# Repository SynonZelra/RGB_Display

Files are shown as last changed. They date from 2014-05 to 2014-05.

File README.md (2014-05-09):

RGB Display
===========	
During my work term at Lumotune I worked with developed LCD drivers and wanted to try a completely different type of display that I would be able to make on my own so I looked into making a RGB display. Just like the LED cube, multiplexing and persistence of vision were key techniques required. I used PWM drivers (TLC5940) to drive the specific values to the RGB LEDs in each column and shift registers (CD4094B) to switch between the rows. 
This is the first personal project dealing with complex IC so an online tutorial and base TLC5940 code from Kevin Darrah was used and expanded on: https://www.youtube.com/watch?v=FehBLNHMlfo 

This code was used instead of existing libraries to understand lower level programming and in depth use of TLC5940.
	
Updates:
--------
-	Original design was for 32 columns. This was reduced to 16 columns due to lack of RGB LEDs. The other sections have been updated to take this change into account.

Here is an image of the 16x16 RGB Display:  
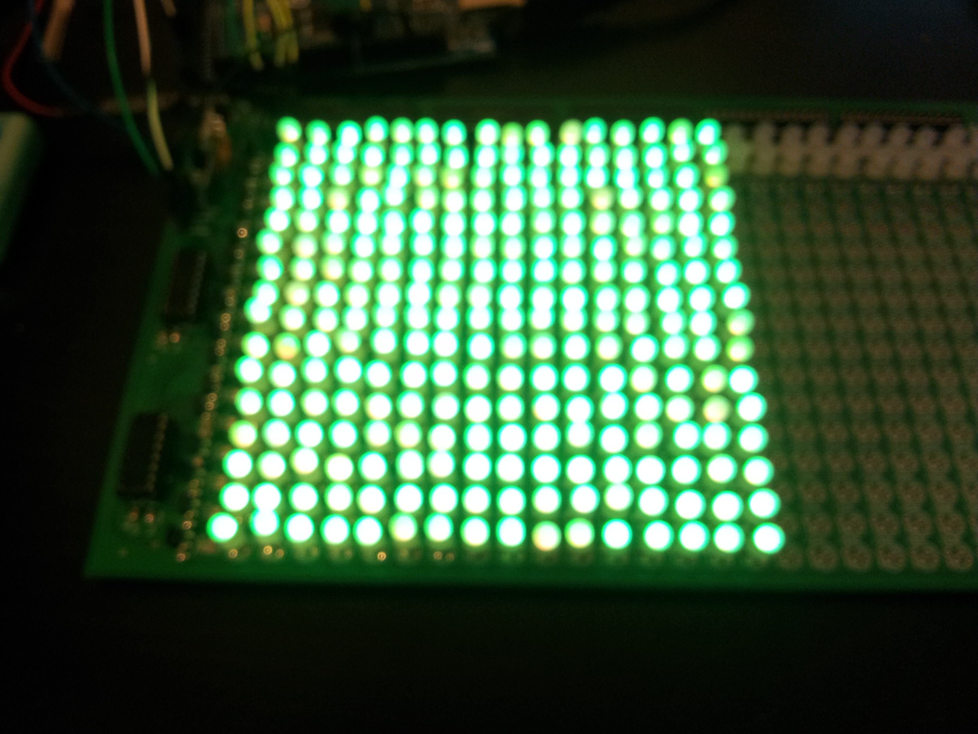
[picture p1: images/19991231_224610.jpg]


Click below for a video of the display:  
<a href="https://youtu.be/2PrOFA3ZqBM">https://youtu.be/2PrOFA3ZqBM</a>

Materials:
----------
(Material list has been updated)
-	x256, 5mm RGB LED
    -	Common anode for PWM driver to sink current, see Figure 1
-	x3, PWM driver [TLC5940](http://www.ti.com/lit/ds/symlink/tlc5940.pdf)
    -	16 channels per chip
    -	12-bit PWM resolution
    -	6-bit dot correction resolution
    -	Current sink
    -	Daisy-chained
-	x2, shift register [CD4094B](http://www.ti.com/lit/ds/symlink/cd4094b.pdf)
    -	8 outputs per chip
    -	Daisy-chained
-	x16, p-channel MOSFET [ZVP4424A](http://www.diodes.com/datasheets/ZVP4424A.pdf) 
-	x5, 0.1uF ceramic capacitor, package 0805
-	x5, 1uF ceramic capacitor, package 0805
-	x2, 10uF tantalum capacitor
-	x1, 5V LDO regulator [LT1096CT](http://cds.linear.com/docs/en/datasheet/1086ffs.pdf)
-	x2, 1x6 female connector header
-	x1, 2.1mm power connector jack
-	x3, 28 position IC socket 
-	Soldering assembly (solder, iron, braid, etc.)
-	Breadboard and jumper wires

Design:
-------
-	LEDs were arranged in an array of 16x16 (256 LEDs, 48 pins per row) addressed by 3 PWM drivers (48 channels) and 2 shift registers (16 outputs)
-	Column data input to PWM drivers through SPI protocol, lighting an entire row at once and row is switched with shift register and new RGB data is sent through PWM driver
-	Shift register can’t source enough current to light 16 LEDs so a p-channel MOSFET is used as a high side switch at each row to source required current
-	Base code from Kevin Darrah included:
    -	8-bit to 12-bit conversion for GS data transmission
    -	SPI protocol and timer interrupt setup 
-	Code was expanded on to include:
    -	Brightness and colour correction
    -	8-bit data resolution for easier storage and processing
    -	Shift register, data buffer and multiplexing
-	Schematic capture and PCB layout designed with CadSoft EAGLE

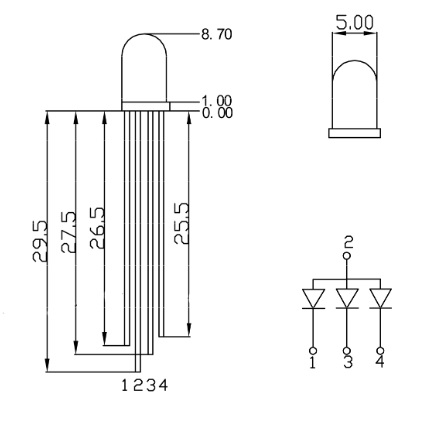
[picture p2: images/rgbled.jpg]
  
Figure 1: Common Anode RGB LED

Assembly:
---------
Prototype and assembly of RGB display can be seen from the images and videos below:  
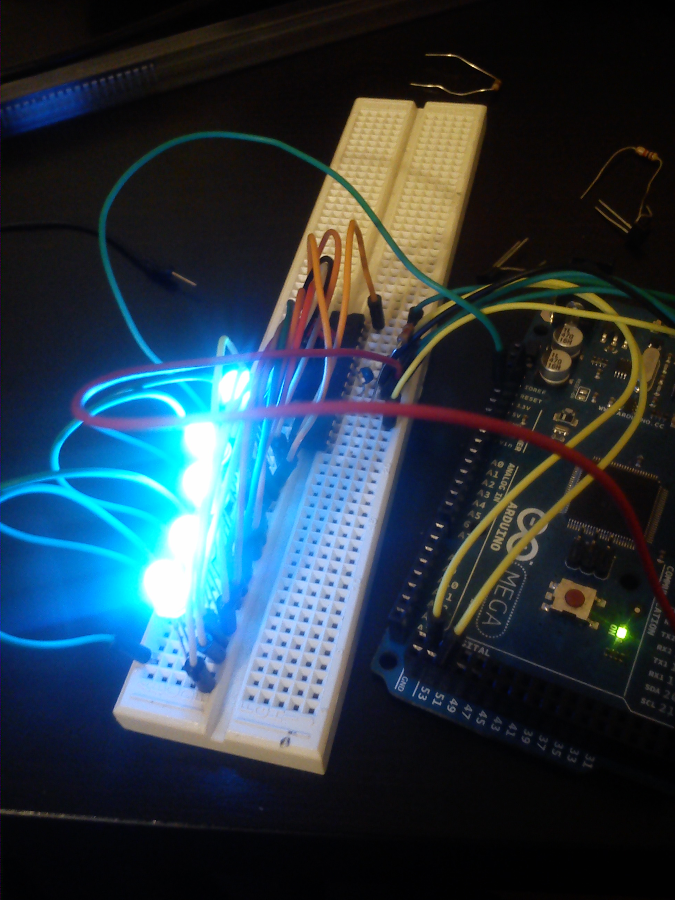
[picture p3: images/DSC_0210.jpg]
  
Figure 2: Testing TLC5940 

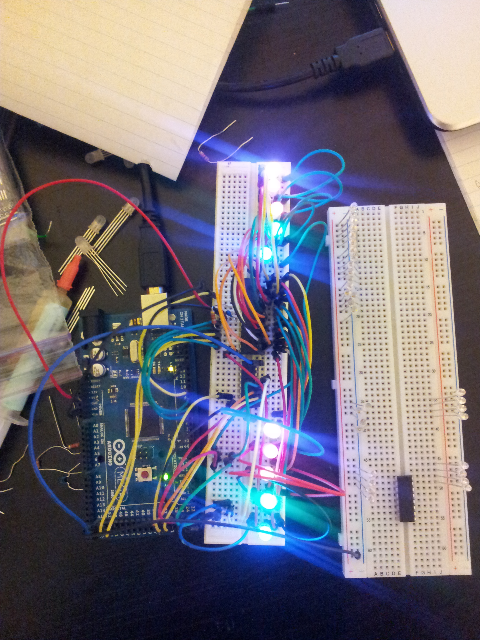
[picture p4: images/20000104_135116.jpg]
  
Figure 3: 0000104_135116, Testing 2 row multiplexing with TLC5940 and CD4094B  

<a href="https://youtu.be/0XYK6YoSBJY">https://youtu.be/0XYK6YoSBJY</a>  
Video 1: TLCCycle2, Video of cycling through all the colours with TLC5940

<a href="https://youtu.be/0XYK6YoSBJY">https://youtu.be/0XYK6YoSBJY</a>  
Video 2: TLCShift, Video of shifting colours with TLC5940

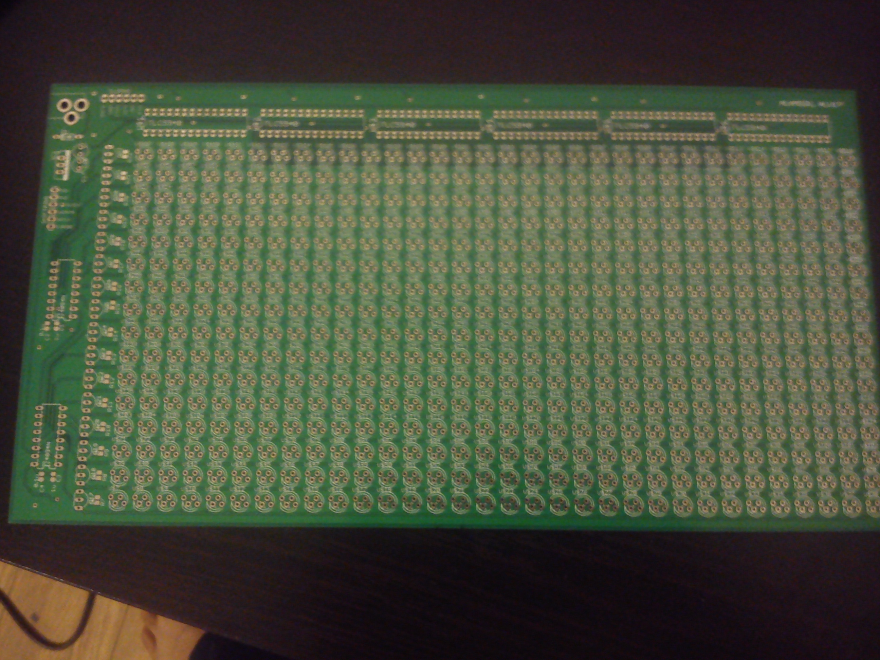
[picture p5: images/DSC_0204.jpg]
  
Figure 4: PCB from SeeedStudio

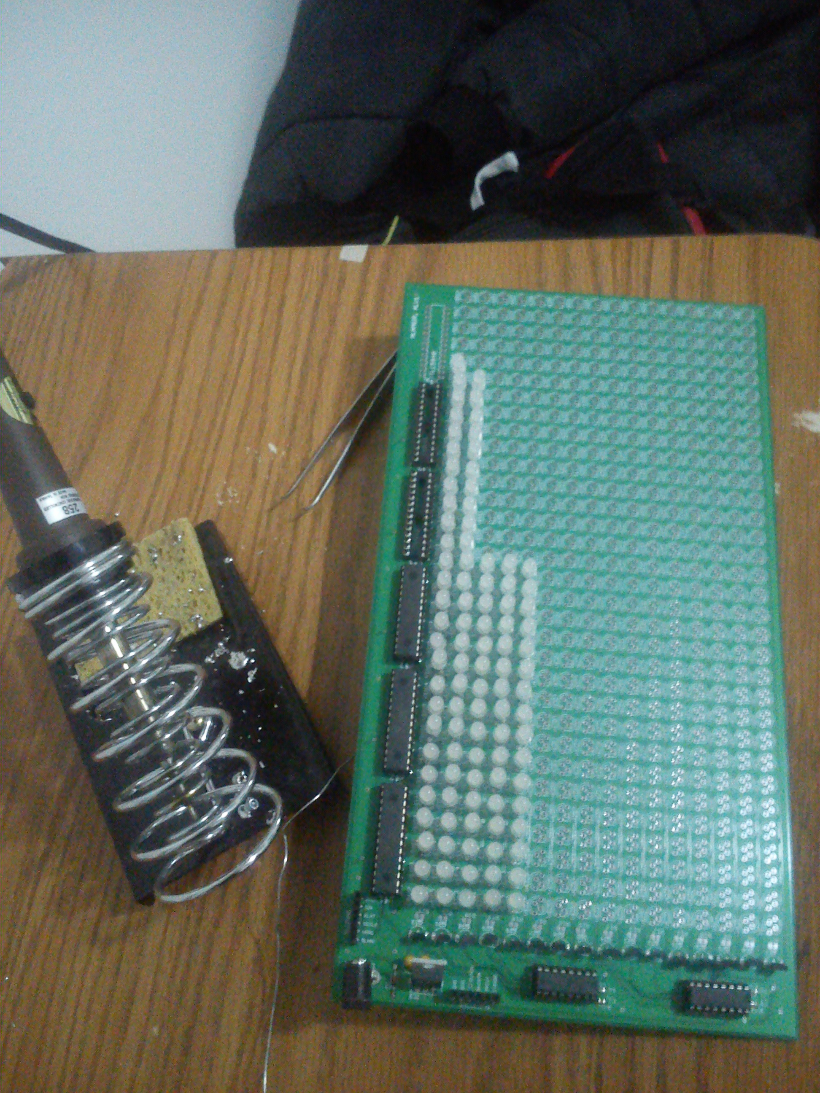
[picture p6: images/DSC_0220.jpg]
  
Figure 5: Soldering the PCB

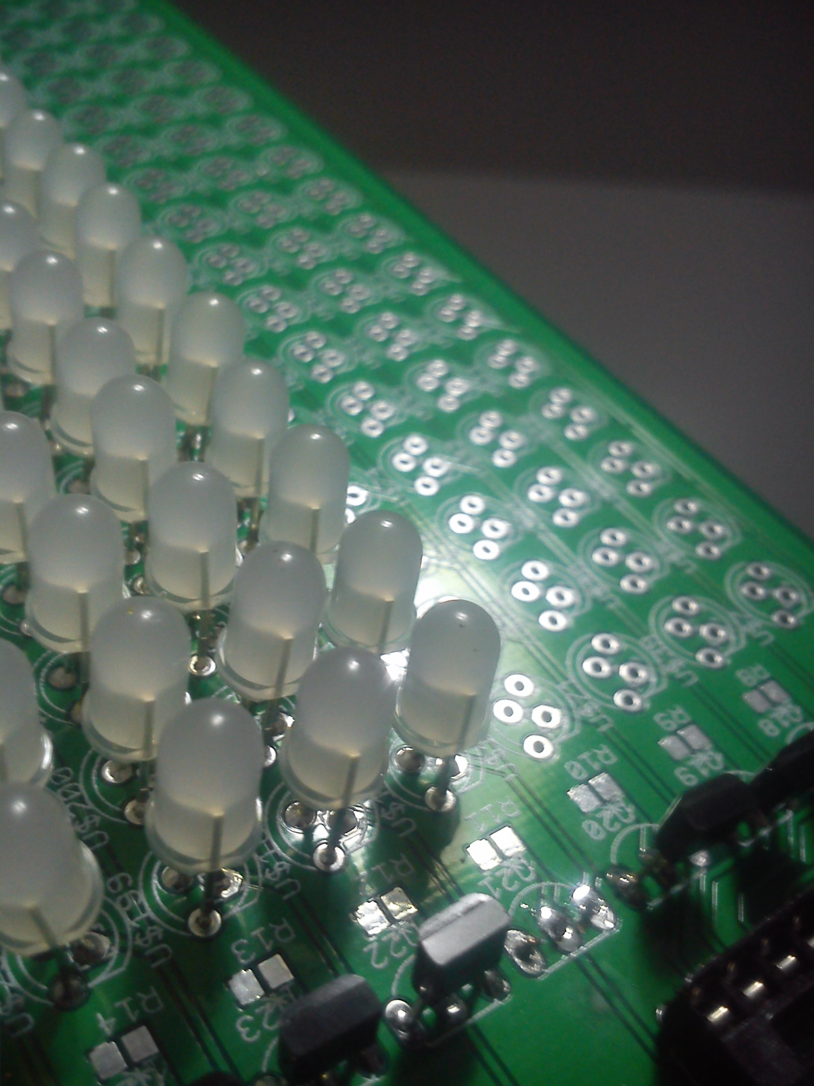
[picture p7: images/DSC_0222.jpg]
  
Figure 6: Testing and debugging the board (malfunctioning MOSFET) while soldering 

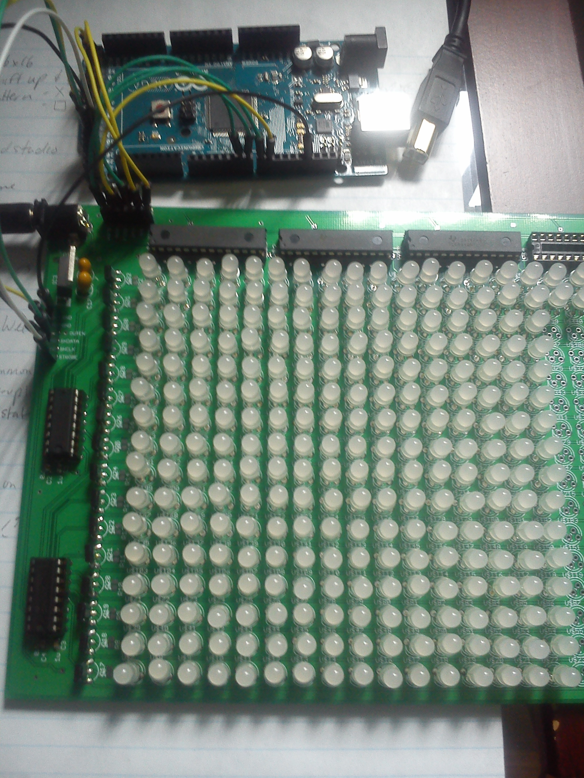
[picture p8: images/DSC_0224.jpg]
  
Figure 7: 16x16 RGB LED soldered!

Future:
-------
-	Update software to use TLC5940 and TLC5940Mux libraries
-	Import images with Python through serial port and show on RGB display

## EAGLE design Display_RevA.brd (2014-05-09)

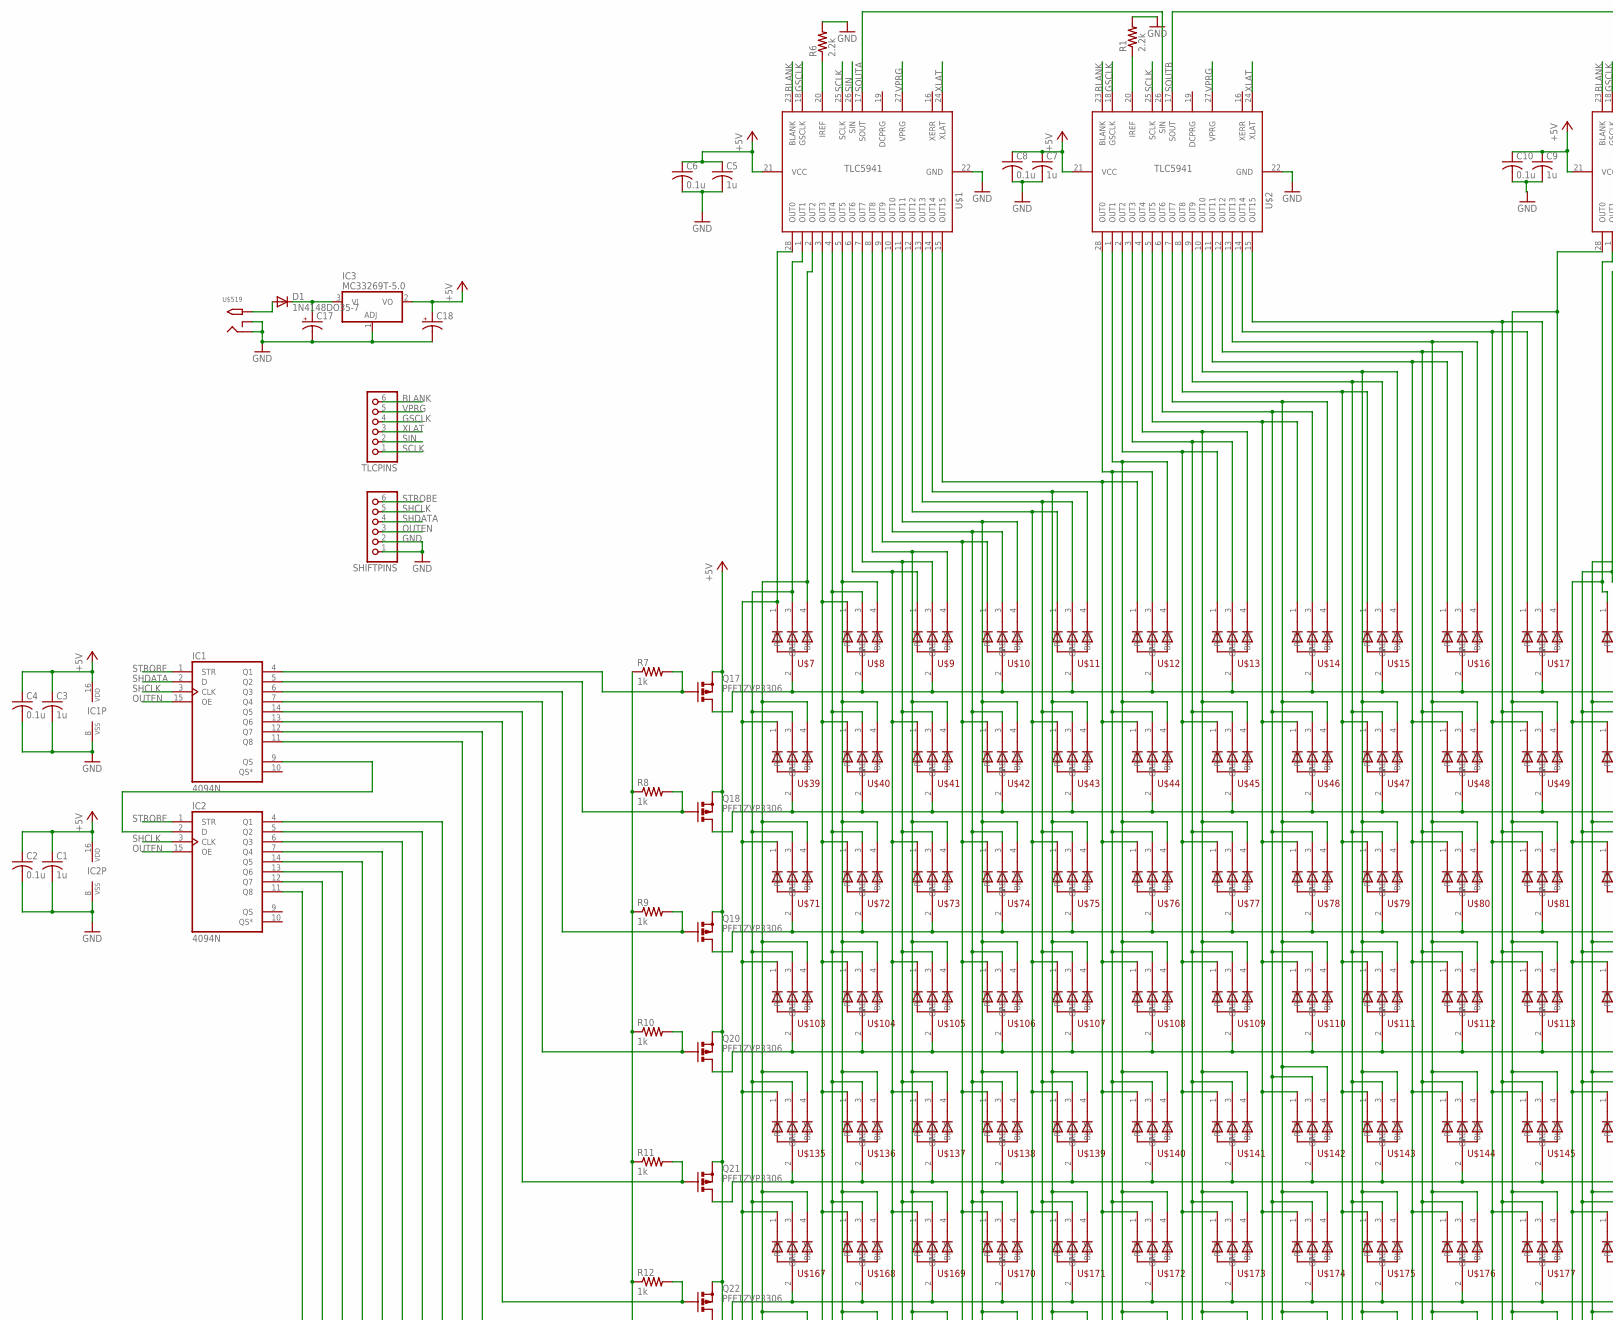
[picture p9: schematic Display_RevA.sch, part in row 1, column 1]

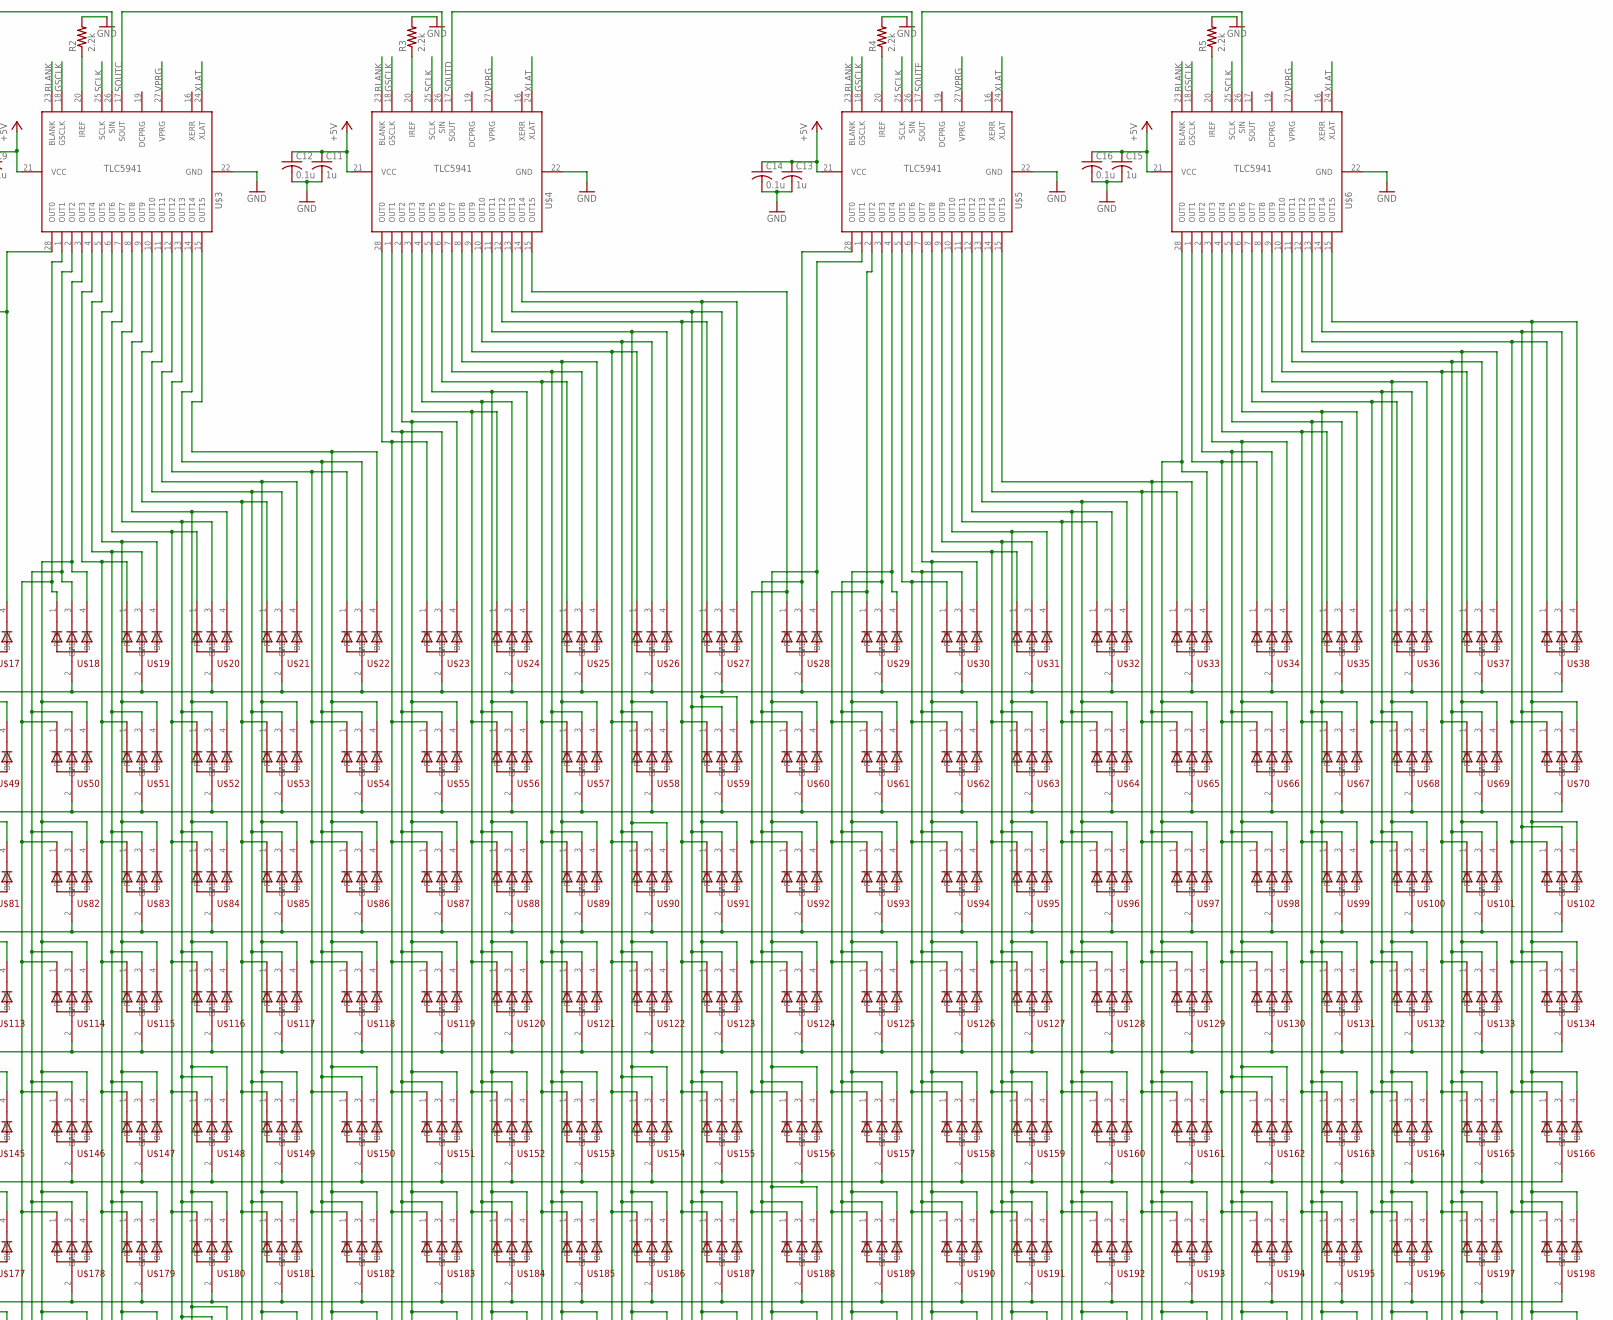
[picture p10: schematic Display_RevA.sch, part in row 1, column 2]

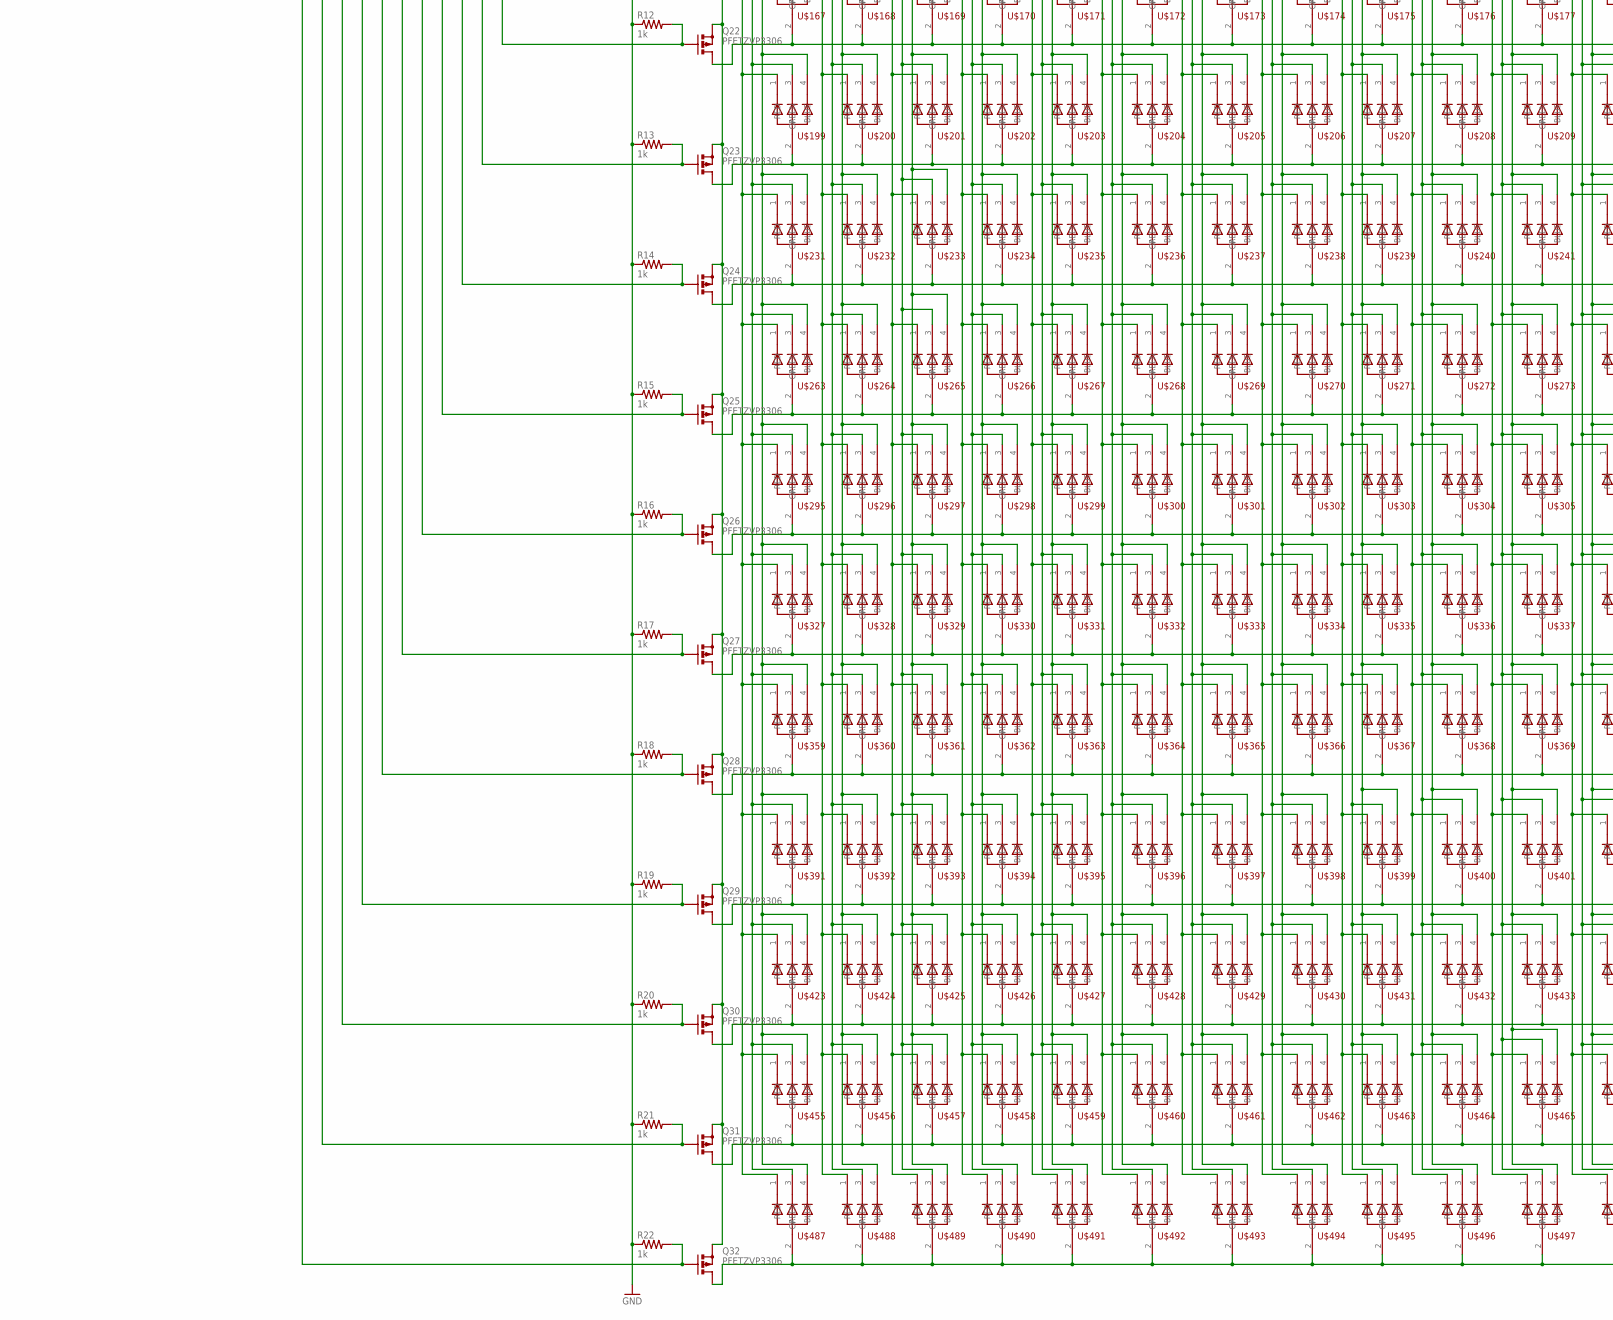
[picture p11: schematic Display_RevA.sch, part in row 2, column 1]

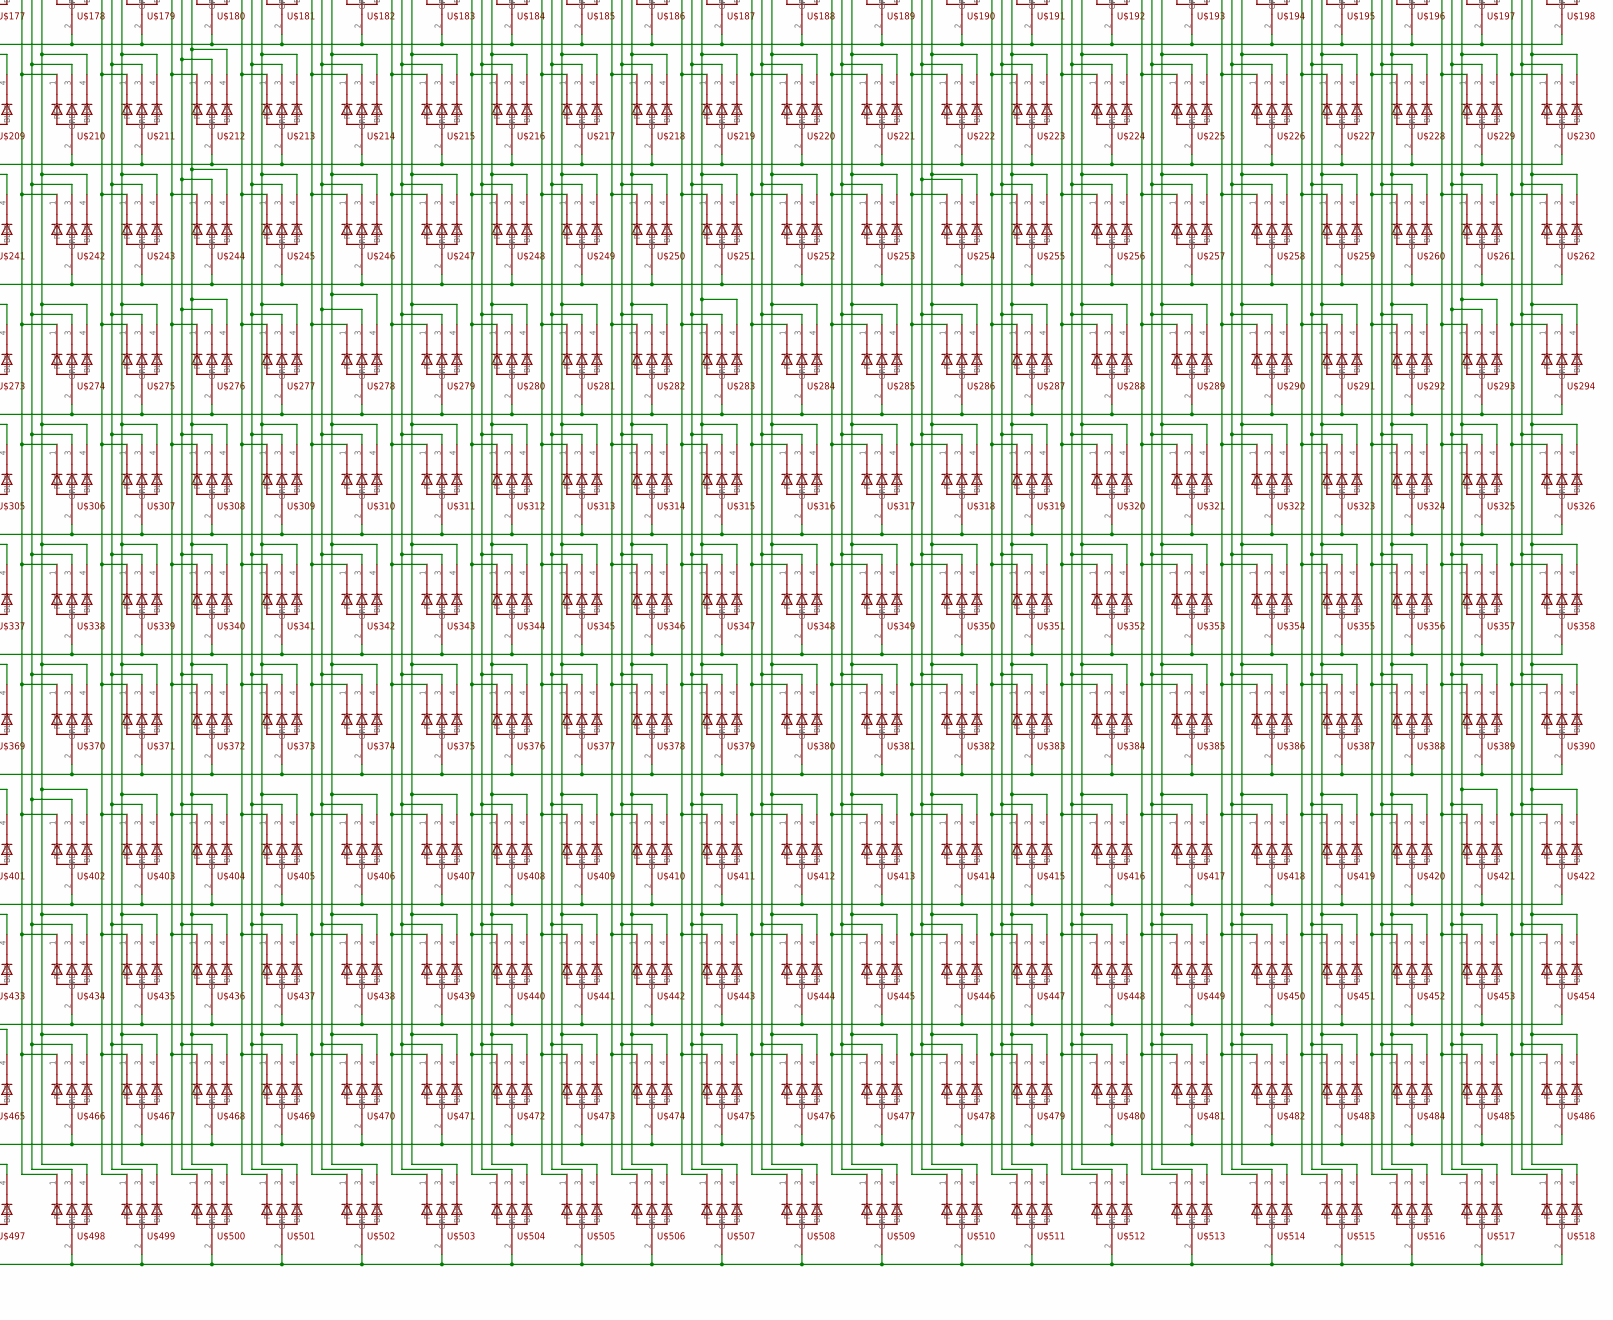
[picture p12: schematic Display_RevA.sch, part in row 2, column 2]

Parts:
C1, C3, C5, C7, C9, C11, C13, C15: 1u; C0805
C2, C4, C6, C8, C10, C12, C14, C16: 0.1u; C0805
C17, C18: CPOL-USE2.5-5; E2,5-5
D1: 1N4148DO35-7; DO35-7
IC1, IC2: 4094N; DIL16
IC3: MC33269T-5.0; TO220V
Q17, Q18, Q19, Q20, Q21, Q22, Q23, Q24, Q25, Q26, Q27, Q28, Q29, Q30, Q31, Q32: PFETZVP3306; TO92-OVAL
R1, R2, R3, R4, R5, R6: 2.2k; R0805
R7, R8, R9, R10, R11, R12, R13, R14, R15, R16, R17, R18, R19, R20, R21, R22: 1k; R0805
SHIFTPINS: PINHD-1X6; 1X06
TLCPINS: PINHD-1X6; 1X06
U$1, U$2, U$3, U$4, U$5, U$6: TLC5940; DIL28-3
U$7, U$8, U$9, U$10, U$11, U$12, U$13, U$14, U$15, U$16, U$17, U$18, U$19, U$20, U$21, U$22, U$23, U$24, U$25, U$26, U$27, U$28, U$29, U$30, U$31, U$32, U$33, U$34, U$35, U$36, U$37, U$38, U$39, U$40, U$41, U$42, U$43, U$44, U$45, U$46, U$47, U$48, U$49, U$50, U$51, U$52, U$53, U$54, U$55, U$56, U$57, U$58, U$59, U$60, U$61, U$62, U$63, U$64, U$65, U$66, U$67, U$68, U$69, U$70, U$71, U$72, U$73, U$74, U$75, U$76, U$77, U$78, U$79, U$80, U$81, U$82, U$83, U$84, U$85, U$86, U$87, U$88, U$89, U$90, U$91, U$92, U$93, U$94, U$95, U$96, U$97, U$98, U$99, U$100, U$101, U$102, U$103, U$104, U$105, U$106, U$107, U$108, U$109, U$110, U$111, U$112, U$113, U$114, U$115, U$116, U$117, U$118, U$119, U$120, U$121, U$122, U$123, U$124, U$125, U$126, U$127, U$128, U$129, U$130, U$131, U$132, U$133, U$134, U$135, U$136, U$137, U$138, U$139, U$140, U$141, U$142, U$143, U$144, U$145, U$146, U$147, U$148, U$149, U$150, U$151, U$152, U$153, U$154, U$155, U$156, U$157, U$158, U$159, U$160, U$161, U$162, U$163, U$164, U$165, U$166, U$167, U$168, U$169, U$170, U$171, U$172, U$173, U$174, U$175, U$176, U$177, U$178, U$179, U$180, U$181, U$182, U$183, U$184, U$185, U$186, U$187, U$188, U$189, U$190, U$191, U$192, U$193, U$194, U$195, U$196, U$197, U$198, U$199, U$200, U$201, U$202, U$203, U$204, U$205, U$206, U$207, U$208, U$209, U$210, U$211, U$212, U$213, U$214, U$215, U$216, U$217, U$218, U$219, U$220, U$221, U$222, U$223, U$224, U$225, U$226, U$227, U$228, U$229, U$230, U$231, U$232, U$233, U$234, U$235, U$236, U$237, U$238, U$239, U$240, U$241, U$242, U$243, U$244, U$245, U$246, U$247, U$248, U$249, U$250, U$251, U$252, U$253, U$254, U$255, U$256, U$257, U$258, U$259, U$260, U$261, U$262, U$263, U$264, U$265, U$266, U$267, U$268, U$269, U$270, U$271, U$272, U$273, U$274, U$275, U$276, U$277, U$278, U$279, U$280, U$281, U$282, U$283, U$284, U$285, U$286, U$287, U$288, U$289, U$290, U$291, U$292, U$293, U$294, U$295, U$296, U$297, U$298, U$299, U$300, U$301, U$302, U$303, U$304, U$305, U$306, U$307, U$308, U$309, U$310, U$311, U$312, U$313, U$314, U$315, U$316, U$317, U$318, U$319, U$320, U$321, U$322, U$323, U$324, U$325, U$326, U$327, U$328, U$329, U$330, U$331, U$332, U$333, U$334, U$335, U$336, U$337, U$338, U$339, U$340, U$341, U$342, U$343, U$344, U$345, U$346, U$347, U$348, U$349, U$350, U$351, U$352, U$353, U$354, U$355, U$356, U$357, U$358, U$359, U$360, U$361, U$362, U$363, U$364, U$365, U$366, U$367, U$368, U$369, U$370, U$371, U$372, U$373, U$374, U$375, U$376, U$377, U$378, U$379, U$380, U$381, U$382, U$383, U$384, U$385, U$386, U$387, U$388, U$389, U$390, U$391, U$392, U$393, U$394, U$395, U$396, U$397, U$398, U$399, U$400, U$401, U$402, U$403, U$404, U$405, U$406, U$407, U$408, U$409, U$410, U$411, U$412, U$413, U$414, U$415, U$416, U$417, U$418, U$419, U$420, U$421, U$422, U$423, U$424, U$425, U$426, U$427, U$428, U$429, U$430, U$431, U$432, U$433, U$434, U$435, U$436, U$437, U$438, U$439, U$440, U$441, U$442, U$443, U$444, U$445, U$446, U$447, U$448, U$449, U$450, U$451, U$452, U$453, U$454, U$455, U$456, U$457, U$458, U$459, U$460, U$461, U$462, U$463, U$464, U$465, U$466, U$467, U$468, U$469, U$470, U$471, U$472, U$473, U$474, U$475, U$476, U$477, U$478, U$479, U$480, U$481, U$482, U$483, U$484, U$485, U$486, U$487, U$488, U$489, U$490, U$491, U$492, U$493, U$494, U$495, U$496, U$497, U$498, U$499, U$500, U$501, U$502, U$503, U$504, U$505, U$506, U$507, U$508, U$509, U$510, U$511, U$512, U$513, U$514, U$515, U$516, U$517, U$518: RGBLEDAN; LED5MMRGB
U$519: 2.1MMJACKTHM; PJ-102A

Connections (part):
+5V: C1.1, C2.1, C3.1, C4.1, C5.1, C6.1, C7.1, C8.1, C9.1, C10.1, C11.1, C12.1, C13.1, C14.1, C15.1, C16.1, C18.+, IC1.16 (VDD), IC2.16 (VDD), IC3.2 (VO), Q17.1 (S), Q18.1 (S), Q19.1 (S), Q20.1 (S), Q21.1 (S), Q22.1 (S), Q23.1 (S), Q24.1 (S), Q25.1 (S), Q26.1 (S), Q27.1 (S), Q28.1 (S), Q29.1 (S), Q30.1 (S), Q31.1 (S), Q32.1 (S), U$1.21 (VCC), U$2.21 (VCC), U$3.21 (VCC), U$4.21 (VCC), U$5.21 (VCC), U$6.21 (VCC)
BLANK: TLCPINS.6, U$1.23 (BLANK), U$2.23 (BLANK), U$3.23 (BLANK), U$4.23 (BLANK), U$5.23 (BLANK), U$6.23 (BLANK)
GND: C1.2, C2.2, C3.2, C4.2, C5.2, C6.2, C7.2, C8.2, C9.2, C10.2, C11.2, C12.2, C13.2, C14.2, C15.2, C16.2, C17.-, C18.-, IC1.8 (VSS), IC2.8 (VSS), IC3.1 (ADJ), R1.2, R2.2, R3.2, R4.2, R5.2, R6.2, R7.1, R8.1, R9.1, R10.1, R11.1, R12.1, R13.1, R14.1, R15.1, R16.1, R17.1, R18.1, R19.1, R20.1, R21.1, R22.1, SHIFTPINS.1, SHIFTPINS.2, U$1.22 (GND), U$2.22 (GND), U$3.22 (GND), U$4.22 (GND), U$5.22 (GND), U$6.22 (GND), U$519.RING, U$519.RING_SW
GSCLK: TLCPINS.4, U$1.18 (GSCLK), U$2.18 (GSCLK), U$3.18 (GSCLK), U$4.18 (GSCLK), U$5.18 (GSCLK), U$6.18 (GSCLK)
unnamed: IC1.5 (Q2), Q18.2 (G), R8.2
unnamed: Q18.3 (D), U$39.2 (V), U$40.2 (V), U$41.2 (V), U$42.2 (V), U$43.2 (V), U$44.2 (V), U$45.2 (V), U$46.2 (V), U$47.2 (V), U$48.2 (V), U$49.2 (V), U$50.2 (V), U$51.2 (V), U$52.2 (V), U$53.2 (V), U$54.2 (V), U$55.2 (V), U$56.2 (V), U$57.2 (V), U$58.2 (V), U$59.2 (V), U$60.2 (V), U$61.2 (V), U$62.2 (V), U$63.2 (V), U$64.2 (V), U$65.2 (V), U$66.2 (V), U$67.2 (V), U$68.2 (V), U$69.2 (V), U$70.2 (V)
unnamed: IC1.6 (Q3), Q19.2 (G), R9.2
unnamed: Q19.3 (D), U$71.2 (V), U$72.2 (V), U$73.2 (V), U$74.2 (V), U$75.2 (V), U$76.2 (V), U$77.2 (V), U$78.2 (V), U$79.2 (V), U$80.2 (V), U$81.2 (V), U$82.2 (V), U$83.2 (V), U$84.2 (V), U$85.2 (V), U$86.2 (V), U$87.2 (V), U$88.2 (V), U$89.2 (V), U$90.2 (V), U$91.2 (V), U$92.2 (V), U$93.2 (V), U$94.2 (V), U$95.2 (V), U$96.2 (V), U$97.2 (V), U$98.2 (V), U$99.2 (V), U$100.2 (V), U$101.2 (V), U$102.2 (V)
unnamed: IC1.7 (Q4), Q20.2 (G), R10.2
unnamed: Q20.3 (D), U$103.2 (V), U$104.2 (V), U$105.2 (V), U$106.2 (V), U$107.2 (V), U$108.2 (V), U$109.2 (V), U$110.2 (V), U$111.2 (V), U$112.2 (V), U$113.2 (V), U$114.2 (V), U$115.2 (V), U$116.2 (V), U$117.2 (V), U$118.2 (V), U$119.2 (V), U$120.2 (V), U$121.2 (V), U$122.2 (V), U$123.2 (V), U$124.2 (V), U$125.2 (V), U$126.2 (V), U$127.2 (V), U$128.2 (V), U$129.2 (V), U$130.2 (V), U$131.2 (V), U$132.2 (V), U$133.2 (V), U$134.2 (V)
unnamed: IC1.14 (Q5), Q21.2 (G), R11.2
unnamed: Q21.3 (D), U$135.2 (V), U$136.2 (V), U$137.2 (V), U$138.2 (V), U$139.2 (V), U$140.2 (V), U$141.2 (V), U$142.2 (V), U$143.2 (V), U$144.2 (V), U$145.2 (V), U$146.2 (V), U$147.2 (V), U$148.2 (V), U$149.2 (V), U$150.2 (V), U$151.2 (V), U$152.2 (V), U$153.2 (V), U$154.2 (V), U$155.2 (V), U$156.2 (V), U$157.2 (V), U$158.2 (V), U$159.2 (V), U$160.2 (V), U$161.2 (V), U$162.2 (V), U$163.2 (V), U$164.2 (V), U$165.2 (V), U$166.2 (V)
unnamed: IC1.13 (Q6), Q22.2 (G), R12.2
unnamed: Q22.3 (D), U$167.2 (V), U$168.2 (V), U$169.2 (V), U$170.2 (V), U$171.2 (V), U$172.2 (V), U$173.2 (V), U$174.2 (V), U$175.2 (V), U$176.2 (V), U$177.2 (V), U$178.2 (V), U$179.2 (V), U$180.2 (V), U$181.2 (V), U$182.2 (V), U$183.2 (V), U$184.2 (V), U$185.2 (V), U$186.2 (V), U$187.2 (V), U$188.2 (V), U$189.2 (V), U$190.2 (V), U$191.2 (V), U$192.2 (V), U$193.2 (V), U$194.2 (V), U$195.2 (V), U$196.2 (V), U$197.2 (V), U$198.2 (V)
unnamed: IC1.12 (Q7), Q23.2 (G), R13.2
unnamed: Q23.3 (D), U$199.2 (V), U$200.2 (V), U$201.2 (V), U$202.2 (V), U$203.2 (V), U$204.2 (V), U$205.2 (V), U$206.2 (V), U$207.2 (V), U$208.2 (V), U$209.2 (V), U$210.2 (V), U$211.2 (V), U$212.2 (V), U$213.2 (V), U$214.2 (V), U$215.2 (V), U$216.2 (V), U$217.2 (V), U$218.2 (V), U$219.2 (V), U$220.2 (V), U$221.2 (V), U$222.2 (V), U$223.2 (V), U$224.2 (V), U$225.2 (V), U$226.2 (V), U$227.2 (V), U$228.2 (V), U$229.2 (V), U$230.2 (V)
unnamed: IC1.11 (Q8), Q24.2 (G), R14.2
unnamed: Q24.3 (D), U$231.2 (V), U$232.2 (V), U$233.2 (V), U$234.2 (V), U$235.2 (V), U$236.2 (V), U$237.2 (V), U$238.2 (V), U$239.2 (V), U$240.2 (V), U$241.2 (V), U$242.2 (V), U$243.2 (V), U$244.2 (V), U$245.2 (V), U$246.2 (V), U$247.2 (V), U$248.2 (V), U$249.2 (V), U$250.2 (V), U$251.2 (V), U$252.2 (V), U$253.2 (V), U$254.2 (V), U$255.2 (V), U$256.2 (V), U$257.2 (V), U$258.2 (V), U$259.2 (V), U$260.2 (V), U$261.2 (V), U$262.2 (V)
unnamed: IC2.4 (Q1), Q25.2 (G), R15.2
unnamed: IC1.4 (Q1), Q17.2 (G), R7.2
unnamed: Q17.3 (D), U$7.2 (V), U$8.2 (V), U$9.2 (V), U$10.2 (V), U$11.2 (V), U$12.2 (V), U$13.2 (V), U$14.2 (V), U$15.2 (V), U$16.2 (V), U$17.2 (V), U$18.2 (V), U$19.2 (V), U$20.2 (V), U$21.2 (V), U$22.2 (V), U$23.2 (V), U$24.2 (V), U$25.2 (V), U$26.2 (V), U$27.2 (V), U$28.2 (V), U$29.2 (V), U$30.2 (V), U$31.2 (V), U$32.2 (V), U$33.2 (V), U$34.2 (V), U$35.2 (V), U$36.2 (V), U$37.2 (V), U$38.2 (V)
unnamed: Q25.3 (D), U$263.2 (V), U$264.2 (V), U$265.2 (V), U$266.2 (V), U$267.2 (V), U$268.2 (V), U$269.2 (V), U$270.2 (V), U$271.2 (V), U$272.2 (V), U$273.2 (V), U$274.2 (V), U$275.2 (V), U$276.2 (V), U$277.2 (V), U$278.2 (V), U$279.2 (V), U$280.2 (V), U$281.2 (V), U$282.2 (V), U$283.2 (V), U$284.2 (V), U$285.2 (V), U$286.2 (V), U$287.2 (V), U$288.2 (V), U$289.2 (V), U$290.2 (V), U$291.2 (V), U$292.2 (V), U$293.2 (V), U$294.2 (V)
unnamed: IC2.5 (Q2), Q26.2 (G), R16.2
unnamed: Q26.3 (D), U$295.2 (V), U$296.2 (V), U$297.2 (V), U$298.2 (V), U$299.2 (V), U$300.2 (V), U$301.2 (V), U$302.2 (V), U$303.2 (V), U$304.2 (V), U$305.2 (V), U$306.2 (V), U$307.2 (V), U$308.2 (V), U$309.2 (V), U$310.2 (V), U$311.2 (V), U$312.2 (V), U$313.2 (V), U$314.2 (V), U$315.2 (V), U$316.2 (V), U$317.2 (V), U$318.2 (V), U$319.2 (V), U$320.2 (V), U$321.2 (V), U$322.2 (V), U$323.2 (V), U$324.2 (V), U$325.2 (V), U$326.2 (V)
unnamed: IC2.6 (Q3), Q27.2 (G), R17.2
unnamed: Q27.3 (D), U$327.2 (V), U$328.2 (V), U$329.2 (V), U$330.2 (V), U$331.2 (V), U$332.2 (V), U$333.2 (V), U$334.2 (V), U$335.2 (V), U$336.2 (V), U$337.2 (V), U$338.2 (V), U$339.2 (V), U$340.2 (V), U$341.2 (V), U$342.2 (V), U$343.2 (V), U$344.2 (V), U$345.2 (V), U$346.2 (V), U$347.2 (V), U$348.2 (V), U$349.2 (V), U$350.2 (V), U$351.2 (V), U$352.2 (V), U$353.2 (V), U$354.2 (V), U$355.2 (V), U$356.2 (V), U$357.2 (V), U$358.2 (V)
unnamed: IC2.7 (Q4), Q28.2 (G), R18.2
unnamed: Q28.3 (D), U$359.2 (V), U$360.2 (V), U$361.2 (V), U$362.2 (V), U$363.2 (V), U$364.2 (V), U$365.2 (V), U$366.2 (V), U$367.2 (V), U$368.2 (V), U$369.2 (V), U$370.2 (V), U$371.2 (V), U$372.2 (V), U$373.2 (V), U$374.2 (V), U$375.2 (V), U$376.2 (V), U$377.2 (V), U$378.2 (V), U$379.2 (V), U$380.2 (V), U$381.2 (V), U$382.2 (V), U$383.2 (V), U$384.2 (V), U$385.2 (V), U$386.2 (V), U$387.2 (V), U$388.2 (V), U$389.2 (V), U$390.2 (V)
unnamed: IC2.14 (Q5), Q29.2 (G), R19.2
unnamed: Q29.3 (D), U$391.2 (V), U$392.2 (V), U$393.2 (V), U$394.2 (V), U$395.2 (V), U$396.2 (V), U$397.2 (V), U$398.2 (V), U$399.2 (V), U$400.2 (V), U$401.2 (V), U$402.2 (V), U$403.2 (V), U$404.2 (V), U$405.2 (V), U$406.2 (V), U$407.2 (V), U$408.2 (V), U$409.2 (V), U$410.2 (V), U$411.2 (V), U$412.2 (V), U$413.2 (V), U$414.2 (V), U$415.2 (V), U$416.2 (V), U$417.2 (V), U$418.2 (V), U$419.2 (V), U$420.2 (V), U$421.2 (V), U$422.2 (V)
unnamed: IC2.13 (Q6), Q30.2 (G), R20.2
unnamed: Q30.3 (D), U$423.2 (V), U$424.2 (V), U$425.2 (V), U$426.2 (V), U$427.2 (V), U$428.2 (V), U$429.2 (V), U$430.2 (V), U$431.2 (V), U$432.2 (V), U$433.2 (V), U$434.2 (V), U$435.2 (V), U$436.2 (V), U$437.2 (V), U$438.2 (V), U$439.2 (V), U$440.2 (V), U$441.2 (V), U$442.2 (V), U$443.2 (V), U$444.2 (V), U$445.2 (V), U$446.2 (V), U$447.2 (V), U$448.2 (V), U$449.2 (V), U$450.2 (V), U$451.2 (V), U$452.2 (V), U$453.2 (V), U$454.2 (V)
unnamed: IC2.12 (Q7), Q31.2 (G), R21.2
unnamed: Q31.3 (D), U$455.2 (V), U$456.2 (V), U$457.2 (V), U$458.2 (V), U$459.2 (V), U$460.2 (V), U$461.2 (V), U$462.2 (V), U$463.2 (V), U$464.2 (V), U$465.2 (V), U$466.2 (V), U$467.2 (V), U$468.2 (V), U$469.2 (V), U$470.2 (V), U$471.2 (V), U$472.2 (V), U$473.2 (V), U$474.2 (V), U$475.2 (V), U$476.2 (V), U$477.2 (V), U$478.2 (V), U$479.2 (V), U$480.2 (V), U$481.2 (V), U$482.2 (V), U$483.2 (V), U$484.2 (V), U$485.2 (V), U$486.2 (V)
unnamed: IC2.11 (Q8), Q32.2 (G), R22.2
unnamed: Q32.3 (D), U$487.2 (V), U$488.2 (V), U$489.2 (V), U$490.2 (V), U$491.2 (V), U$492.2 (V), U$493.2 (V), U$494.2 (V), U$495.2 (V), U$496.2 (V), U$497.2 (V), U$498.2 (V), U$499.2 (V), U$500.2 (V), U$501.2 (V), U$502.2 (V), U$503.2 (V), U$504.2 (V), U$505.2 (V), U$506.2 (V), U$507.2 (V), U$508.2 (V), U$509.2 (V), U$510.2 (V), U$511.2 (V), U$512.2 (V), U$513.2 (V), U$514.2 (V), U$515.2 (V), U$516.2 (V), U$517.2 (V), U$518.2 (V)
unnamed: U$1.28 (OUT0), U$7.1 (RED), U$39.1 (RED), U$71.1 (RED), U$103.1 (RED), U$135.1 (RED), U$167.1 (RED), U$199.1 (RED), U$231.1 (RED), U$263.1 (RED), U$295.1 (RED), U$327.1 (RED), U$359.1 (RED), U$391.1 (RED), U$423.1 (RED), U$455.1 (RED), U$487.1 (RED)
unnamed: U$1.1 (OUT1), U$7.3 (GREEN), U$39.3 (GREEN), U$71.3 (GREEN), U$103.3 (GREEN), U$135.3 (GREEN), U$167.3 (GREEN), U$199.3 (GREEN), U$231.3 (GREEN), U$263.3 (GREEN), U$295.3 (GREEN), U$327.3 (GREEN), U$359.3 (GREEN), U$391.3 (GREEN), U$423.3 (GREEN), U$455.3 (GREEN), U$487.3 (GREEN)
unnamed: U$1.2 (OUT2), U$7.4 (BLUE), U$39.4 (BLUE), U$71.4 (BLUE), U$103.4 (BLUE), U$135.4 (BLUE), U$167.4 (BLUE), U$199.4 (BLUE), U$231.4 (BLUE), U$263.4 (BLUE), U$295.4 (BLUE), U$327.4 (BLUE), U$359.4 (BLUE), U$391.4 (BLUE), U$423.4 (BLUE), U$455.4 (BLUE), U$487.4 (BLUE)
unnamed: U$1.3 (OUT3), U$8.1 (RED), U$40.1 (RED), U$72.1 (RED), U$104.1 (RED), U$136.1 (RED), U$168.1 (RED), U$200.1 (RED), U$232.1 (RED), U$264.1 (RED), U$296.1 (RED), U$328.1 (RED), U$360.1 (RED), U$392.1 (RED), U$424.1 (RED), U$456.1 (RED), U$488.1 (RED)
unnamed: IC1.9 (QS), IC2.2 (D)
unnamed: U$1.4 (OUT4), U$8.3 (GREEN), U$40.3 (GREEN), U$72.3 (GREEN), U$104.3 (GREEN), U$136.3 (GREEN), U$168.3 (GREEN), U$200.3 (GREEN), U$232.3 (GREEN), U$264.3 (GREEN), U$296.3 (GREEN), U$328.3 (GREEN), U$360.3 (GREEN), U$392.3 (GREEN), U$424.3 (GREEN), U$456.3 (GREEN), U$488.3 (GREEN)
unnamed: U$1.5 (OUT5), U$8.4 (BLUE), U$40.4 (BLUE), U$72.4 (BLUE), U$104.4 (BLUE), U$136.4 (BLUE), U$168.4 (BLUE), U$200.4 (BLUE), U$232.4 (BLUE), U$264.4 (BLUE), U$296.4 (BLUE), U$328.4 (BLUE), U$360.4 (BLUE), U$392.4 (BLUE), U$424.4 (BLUE), U$456.4 (BLUE), U$488.4 (BLUE)
unnamed: U$1.6 (OUT6), U$9.1 (RED), U$41.1 (RED), U$73.1 (RED), U$105.1 (RED), U$137.1 (RED), U$169.1 (RED), U$201.1 (RED), U$233.1 (RED), U$265.1 (RED), U$297.1 (RED), U$329.1 (RED), U$361.1 (RED), U$393.1 (RED), U$425.1 (RED), U$457.1 (RED), U$489.1 (RED)
unnamed: U$1.7 (OUT7), U$9.3 (GREEN), U$41.3 (GREEN), U$73.3 (GREEN), U$105.3 (GREEN), U$137.3 (GREEN), U$169.3 (GREEN), U$201.3 (GREEN), U$233.3 (GREEN), U$265.3 (GREEN), U$297.3 (GREEN), U$329.3 (GREEN), U$361.3 (GREEN), U$393.3 (GREEN), U$425.3 (GREEN), U$457.3 (GREEN), U$489.3 (GREEN)
unnamed: U$1.8 (OUT8), U$9.4 (BLUE), U$41.4 (BLUE), U$73.4 (BLUE), U$105.4 (BLUE), U$137.4 (BLUE), U$169.4 (BLUE), U$201.4 (BLUE), U$233.4 (BLUE), U$265.4 (BLUE), U$297.4 (BLUE), U$329.4 (BLUE), U$361.4 (BLUE), U$393.4 (BLUE), U$425.4 (BLUE), U$457.4 (BLUE), U$489.4 (BLUE)
unnamed: U$1.9 (OUT9), U$10.1 (RED), U$42.1 (RED), U$74.1 (RED), U$106.1 (RED), U$138.1 (RED), U$170.1 (RED), U$202.1 (RED), U$234.1 (RED), U$266.1 (RED), U$298.1 (RED), U$330.1 (RED), U$362.1 (RED), U$394.1 (RED), U$426.1 (RED), U$458.1 (RED), U$490.1 (RED)
unnamed: U$1.10 (OUT10), U$10.3 (GREEN), U$42.3 (GREEN), U$74.3 (GREEN), U$106.3 (GREEN), U$138.3 (GREEN), U$170.3 (GREEN), U$202.3 (GREEN), U$234.3 (GREEN), U$266.3 (GREEN), U$298.3 (GREEN), U$330.3 (GREEN), U$362.3 (GREEN), U$394.3 (GREEN), U$426.3 (GREEN), U$458.3 (GREEN), U$490.3 (GREEN)
unnamed: U$1.11 (OUT11), U$10.4 (BLUE), U$42.4 (BLUE), U$74.4 (BLUE), U$106.4 (BLUE), U$138.4 (BLUE), U$170.4 (BLUE), U$202.4 (BLUE), U$234.4 (BLUE), U$266.4 (BLUE), U$298.4 (BLUE), U$330.4 (BLUE), U$362.4 (BLUE), U$394.4 (BLUE), U$426.4 (BLUE), U$458.4 (BLUE), U$490.4 (BLUE)
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

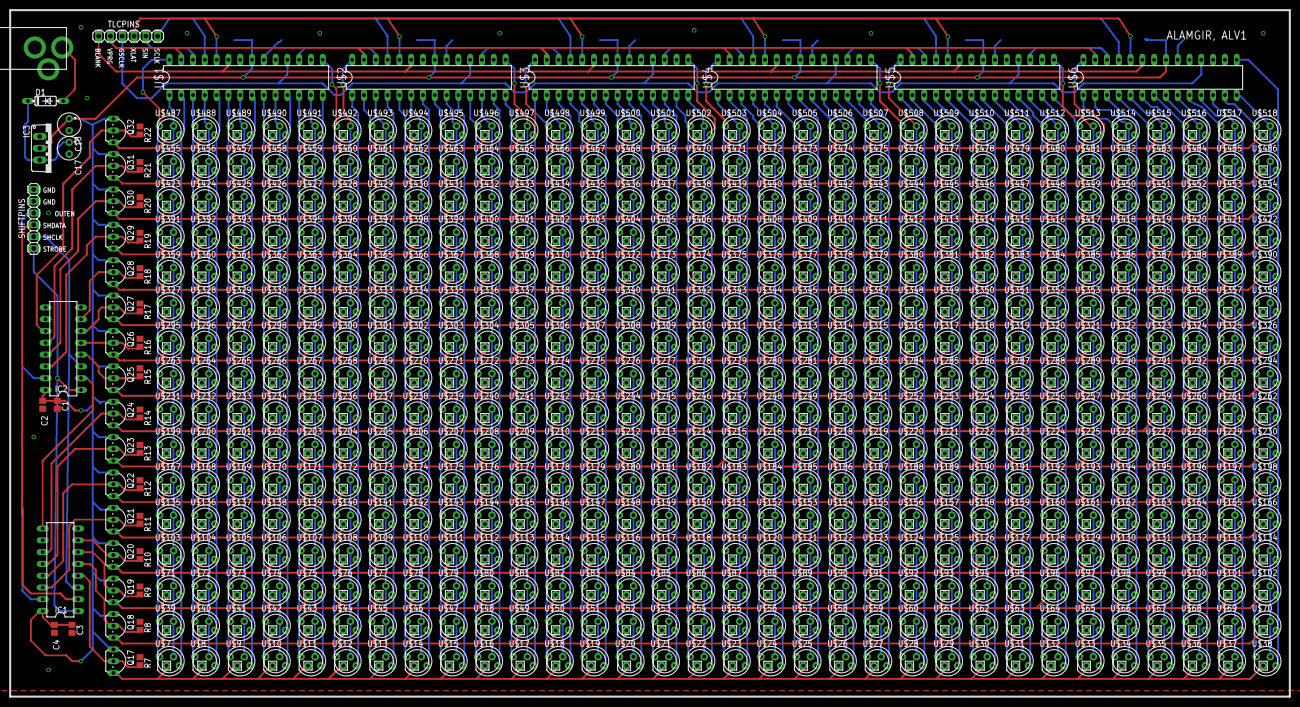
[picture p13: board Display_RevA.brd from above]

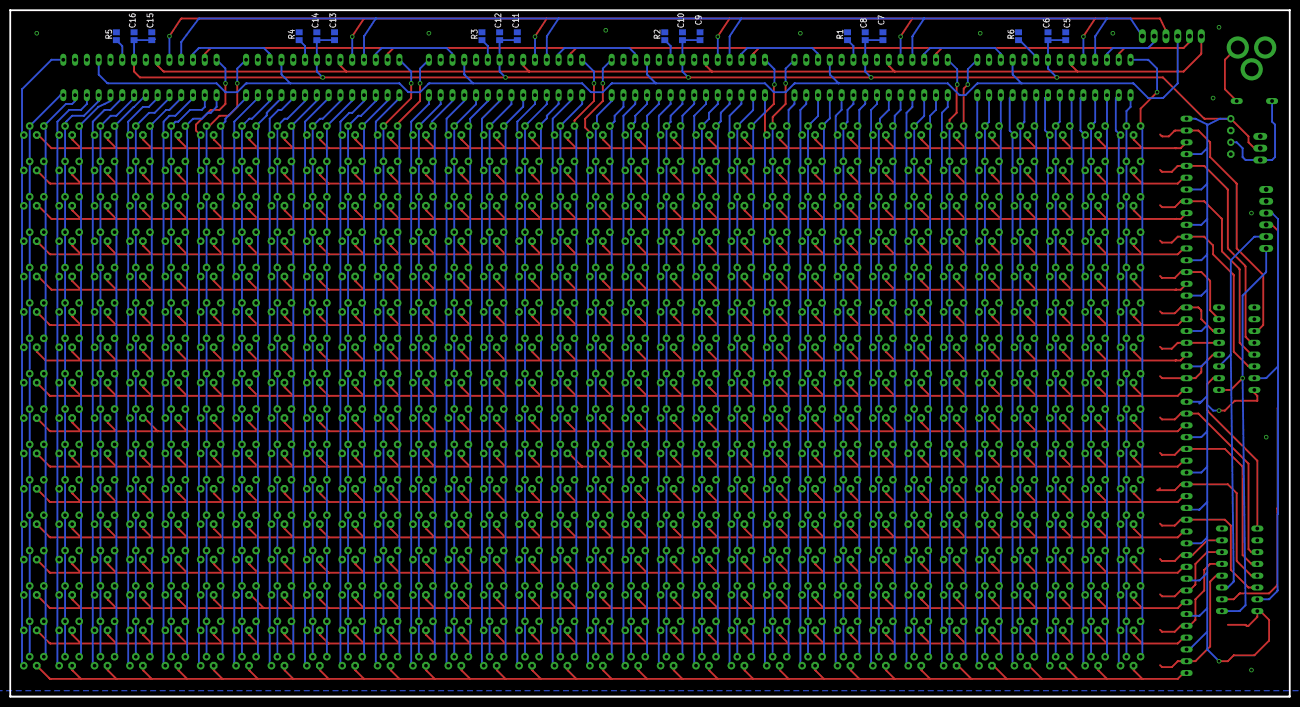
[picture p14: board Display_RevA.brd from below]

Board: 2 copper layers, 275.6 x 147.8 mm, 581 parts (18 on the bottom side), 154 nets.

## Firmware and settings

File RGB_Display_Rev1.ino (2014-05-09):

// Base Code from kdarrah, https://www.youtube.com/user/kdarrah1234

#include <SPI.h>

byte ch=0, chbit=0, spibit=0, spibyte=0;  // variables used by tlc sub routine
int SINData;                              //variable used to shift data to the TLC
// 12-bit resolution for grayscale data, 6-bit resolution for dot correction data

const int totalCols = 48;  // Total channels 
const int totalRows = 16;  // Total rows
const int byteCount = 72;  // Bytes needed for 12-bit data of one row

int displayRow = 0;        // row currently being displayed through tlc
int rowDelay = 0;          // counter for row switching


const byte greenMax = 11110000;    // max green output value
const byte blueMax = 11111111;     // max blue output value
const byte redMax = 01111111;      // max red output value

float brightness = 0.5;            // brightness ratio

// 8-bit resolution allows for each channel to be addressed by 1 byte
const int pwmRes = 256;            // 8 bit PWM resolution
byte newRowBytes[totalRows][48] = {0};       // New data to write to rows

// 3D array for sending out data to TLC
// Updating/Display Array || Rows || 12-bit channel data
// 2 array, one that is currently being displayed and the other is being updated. At the end of the cycle
// the indexes are switched. Considered pointer here instead but it was too slow
byte transferBytes[2][totalRows][byteCount] = {0};
int displayIndex = 0;
int updateIndex = 1;

boolean registers[totalRows];  // array holding the shift register output data for initiliazation 

byte DCvalue[totalCols];      //0-63, 6 bit DOT Correction Bytes

//*******************************************************************************************
//*******************************************************************************************
void setup(){//   MAIN SETUP   MAIN SETUP   MAIN SETUP   MAIN SETUP   MAIN SETUP

  pinMode(6, OUTPUT);//XLAT
  pinMode(9, OUTPUT);//OC2B GSCLK Timer2 (oscillating the pin at 8MHz). OC2B is pin 9
  pinMode(8, OUTPUT);//VPRG
  pinMode(51, OUTPUT);//MOSI DATA, SIN. Must be pin 51
  pinMode(52, OUTPUT);//SPI Clock, SCLK. Must be pin 52

  pinMode(30,OUTPUT);  // strobePin, PC7
  pinMode(31,OUTPUT);  // dataPin, PC6
  pinMode(32,OUTPUT);  // shiftClock, PC5
  pinMode(33,OUTPUT);  // outEnPin, PC4

  //Set up the SPI
  SPI.setBitOrder(MSBFIRST);//Most Significant Bit First
  SPI.setDataMode(SPI_MODE0);// Mode 0 Rising edge of data, keep clock low when idle

  // Clock data in by a multiple of the clock for input data by SPI
  SPI.setClockDivider(SPI_CLOCK_DIV4);//Run the data in at 16MHz/4 - 4MHz

  for(int j=0; j<totalRows; j++){
    for(i=0; i<byteCount; i++)//clear out Gray Scale Data
      transferBytes[0][j][i]=0; 
      transferBytes[1][j][i]=0; 
  }

  for(i=0; i<totalCols; i++){//set Dot Correction data to max (63 decimal for 6 bit)
      DCvalue[i]=63;  
  }

  Serial.begin(115200);//debugging

  //set up DOT Correction
  DotCorrection();// sub routine helps 

  noInterrupts();// set up the counters, so don't go into interrupts

    // Timer2 for grayscale clock. Timer1 to get end of grayscale cycle

  // Using Timer 2 to oscillate the grayscale pin 
  // Toggle OC2B on Compare Match
  // Clear Timer on Compare (CTC) Match mode where OCR2A is the TOP value to reach 
  // Cleared to zero when TOP is reached
  TCCR2A=B00010010;//Timer 2 set to Compare Mode Toggling pin 5 @ 8MHz, Arduino Digital 3
  // TIMER 2 IS GSCLCK
  //Timer 2 prescaler set to 1, 16/1=16 MHz, but toggles pin 5 every other cycle, 8MHz
  TCCR2B=B00000001;

  TCCR1A=B00000000;//Timer 1 doesn't toggle anything, used for counting
  //Timer 1 prescaler set to Fclk/256 
  //Why? We need to count 4096 pulses out of Timer 2 - pin 5
  //8 MHz = 1 pulse every 125ns - - 4096 pulses would need 512us
  //Timer 1 runs at 16MHz/256=62.5kHz, we need a match at every 512us
  //Basically, I can get an interrupt to get called every 512us, so...
  // I need to run Timer 2 @ 8MHz for 512us to get 4096 pulses
  // I can't count those pulses directy (too fast) , so
  // I'll count using Timer 1, which makes a count every 16us
  // The counter starts at 0, so we'll set it to 31 to get an interrupt after 512us
  TCCR1B=B00001100;//Mode=CTC with OSCR1A = TOP and 256 as the prescaler

  // Interrupt. When you get the compare match to A, you want it to go to the interrupt A(?)
  // Mask set up, will call ISR (Inerrupt Service Routine) for Compare match on A
  TIMSK1=B00000010;
  //These are the match values for the counters
  // 0 here means it will match on one cycle of the clock/prescaler

  OCR1A= 31;//to get our 512us Interrupt

  interrupts();// kick off the timers!

  tlcRow(0);  // sends zeros to tlc for setup 

  setupRegisters();

  pinMode(7, OUTPUT);//BLANK  We set this pin up here, so it remains in a high impedance
  // state throughout the setup, otherwise the LEDs go crazy!  even if you write this HIGH

}// END OF SETUP END OF SETUP END OF SETUP END OF SETUP END OF SETUP END OF SETUP END OF SETUP
//******************************************************************************************

//*******************************************************************************************
// INTERRUPTS   INTERRUPTS   INTERRUPTS   INTERRUPTS   INTERRUPTS   INTERRUPTS   INTERRUPTS  
ISR(TIMER1_OVF_vect){
}// Over Limit Flag Interrupt  you need this even if you don't use it

ISR(TIMER1_COMPB_vect){ 
}// Compare B - Not Used

ISR(TIMER1_COMPA_vect){ // Interrupt to count 4096 Pulses on GSLCK
  // Switches row output every other interrupt
  if (rowDelay == 1){
    resetRowOutput();  // prevents bleeding
    nextRow();
    rowDelay = 0;
  }
  else{
    displayOutputs();
    rowDelay++;
  }


}//INTERRUPTS END  INTERRUPTS END  INTERRUPTS END  INTERRUPTS END  INTERRUPTS END  INTERRUPTS END  
//*******************************************************************************************
void loop(){//   MAIN LOOP   MAIN LOOP   MAIN LOOP   MAIN LOOP   MAIN LOOP   MAIN LOOP
  cycleAllColours();
}//      loop close    loop close      loop close      loop close

// ----- PATTERNS ----- \\

// Sets a colour to column A in each row and shifts it over
void shiftTest(){
  static boolean setFlag = true;
  static int currentCol = 0;
  if (setFlag){
    newRowBytes[0][0] = redMax;//black
    newRowBytes[0][1] = greenMax;
    newRowBytes[0][2] = blueMax;
    
    newRowBytes[1][0] = redMax;//red
    newRowBytes[1][1] = 0;
    newRowBytes[1][2] = 0;
    
    newRowBytes[2][0] = 0;//green
    newRowBytes[2][1] = greenMax;
    newRowBytes[2][2] = 0;
    
    newRowBytes[3][0] = 0;//blue
    newRowBytes[3][1] = 0;
    newRowBytes[3][2] = blueMax;
    
    newRowBytes[4][0] = redMax;//white
    newRowBytes[4][1] = greenMax;
    newRowBytes[4][2] = blueMax;
    
    newRowBytes[5][0] = redMax;//purple
    newRowBytes[5][1] = 0;
    newRowBytes[5][2] = blueMax;
    
    newRowBytes[6][0] = 0;//sky blue
    newRowBytes[6][1] = greenMax;
    newRowBytes[6][2] = blueMax;
    
    newRowBytes[7][0] = redMax;//lime green
    newRowBytes[7][1] = greenMax;
    newRowBytes[7][2] = 0;
    
    newRowBytes[8][0] = 0;//teal
    newRowBytes[8][1] = greenMax;
    newRowBytes[8][2] = blueMax*0.1;
    
    newRowBytes[9][0] = redMax;//orange
    newRowBytes[9][1] = greenMax*0.1;
    newRowBytes[9][2] = 0;
    
    newRowBytes[10][0] = 0;//black
    newRowBytes[10][1] = 0;
    newRowBytes[10][2] = 0;
    
    newRowBytes[11][0] = redMax;//yellow?
    newRowBytes[11][1] = greenMax*0.25;
    newRowBytes[11][2] = 0;
    
    newRowBytes[12][0] = redMax;
    newRowBytes[12][1] = 0;
    newRowBytes[12][2] = 0;
    
    newRowBytes[13][0] = 0;
    newRowBytes[13][1] = greenMax;
    newRowBytes[13][2] = 0;
    
    newRowBytes[14][0] = 0;
    newRowBytes[14][1] = 0;
    newRowBytes[14][2] = blueMax;
    
    newRowBytes[15][0] = redMax;
    newRowBytes[15][1] = greenMax;
    newRowBytes[15][2] = blueMax;
    delay(2000);
    setFlag = false;
  }
  else{
    for (int i=0; i<totalRows; i++){
      shiftRight(i);
      newRowBytes[i][0*currentCol] = 0;
      newRowBytes[i][0*currentCol+1] = 0;
      newRowBytes[i][0*currentCol+2] = 0;
      currentCol++;
      delay(1);
    }
  }
  // Updates slightly faster if update through hardcode instead of for loop
  tlcRow(0);
  tlcRow(1);
  tlcRow(2);
  tlcRow(3);
  tlcRow(4);
  tlcRow(5);
  tlcRow(6);
  tlcRow(7);
  tlcRow(8);
  tlcRow(9);
  tlcRow(10);
  tlcRow(11);
  tlcRow(12);
  tlcRow(13);
  tlcRow(14);
  tlcRow(15);
  updateOutputs();
}

void cycleAllColours(){
  int redVal = 0;
  int greenVal = 0;
  int blueVal = 0;
  int changeRate = 20;

  // FADE UP 

  while (blueVal < blueMax){
    for (int i=0; i<totalCols; i+=3){
      newRowBytes[0][i] = redVal;
      newRowBytes[0][i+1] = greenVal;
      newRowBytes[0][i+2] = blueVal;
      newRowBytes[1][i] = redVal;
      newRowBytes[1][i+1] = greenVal;
      newRowBytes[1][i+2] = blueVal;
    }
    blueVal += changeRate;
    tlcRow(0);
    tlcRow(1);
  }
  delay(500);
  blueVal = blueMax;


  delay(500); 
  blueVal = blueMax;

  while (greenVal < greenMax){
    for (int i=0; i<totalCols; i+=3){
      newRowBytes[0][i] = redVal;
      newRowBytes[0][i+1] = greenVal;
      newRowBytes[0][i+2] = blueVal;
      newRowBytes[1][i] = redVal;
      newRowBytes[1][i+1] = greenVal;
      newRowBytes[1][i+2] = blueVal;
    }
    greenVal += changeRate;
    tlcRow(0);
    tlcRow(1);
  }
  delay(500);
  greenVal = greenMax;

  while (blueVal > -1){
    for (int i=0; i<totalCols; i+=3){
      newRowBytes[0][i] = redVal;
      newRowBytes[0][i+1] = greenVal;
      newRowBytes[0][i+2] = blueVal;
      newRowBytes[1][i] = redVal;
      newRowBytes[1][i+1] = greenVal;
      newRowBytes[1][i+2] = blueVal;
    }
    blueVal -= changeRate;
    tlcRow(0);
    tlcRow(1);
  }
  delay(500);
  blueVal = 0;

  while (redVal < redMax){
    for (int i=0; i<totalCols; i+=3){
      newRowBytes[0][i] = redVal;
      newRowBytes[0][i+1] = greenVal;
      newRowBytes[0][i+2] = blueVal;
      newRowBytes[1][i] = redVal;
      newRowBytes[1][i+1] = greenVal;
      newRowBytes[1][i+2] = blueVal;
    }
    redVal += changeRate/2;
    tlcRow(0);
    tlcRow(1);
  }
  delay(500);
  redVal = redMax;

  while (greenVal > -1){
    for (int i=0; i<totalCols; i+=3){
      newRowBytes[0][i] = redVal;
      newRowBytes[0][i+1] = greenVal;
      newRowBytes[0][i+2] = blueVal;
      newRowBytes[1][i] = redVal;
      newRowBytes[1][i+1] = greenVal;
      newRowBytes[1][i+2] = blueVal;
    }
    greenVal -= changeRate;
    tlcRow(0);
    tlcRow(1);
  }
  delay(500);
  greenVal = 0; 

  while (blueVal < blueMax){
    for (int i=0; i<totalCols; i+=3){
      newRowBytes[0][i] = redVal;
      newRowBytes[0][i+1] = greenVal;
      newRowBytes[0][i+2] = blueVal;
      newRowBytes[1][i] = redVal;
      newRowBytes[1][i+1] = greenVal;
      newRowBytes[1][i+2] = blueVal;
    }
    blueVal += changeRate;
    tlcRow(0);
    tlcRow(1);
  }
  delay(500);
  blueVal = blueMax;

  greenVal = greenMax;
  
  delay(5000);

  // Fade Down
  while (greenVal > -1){
    for (int i=0; i<totalCols; i+=3){
      newRowBytes[0][i] = redVal;
      newRowBytes[0][i+1] = greenVal;
      newRowBytes[0][i+2] = blueVal;
      newRowBytes[1][i] = redVal;
      newRowBytes[1][i+1] = greenVal;
      newRowBytes[1][i+2] = blueVal;
    }
    greenVal -= changeRate;
    tlcRow(0);
    tlcRow(1);
  }
  delay(500);
  greenVal = 0;

  while (blueVal > -1){
    for (int i=0; i<totalCols; i+=3){
      newRowBytes[0][i] = redVal;
      newRowBytes[0][i+1] = greenVal;
      newRowBytes[0][i+2] = blueVal;
      newRowBytes[1][i] = redVal;
      newRowBytes[1][i+1] = greenVal;
      newRowBytes[1][i+2] = blueVal;
    }
    blueVal -= changeRate;
    tlcRow(0);
    tlcRow(1);
  }
  delay(500);
  blueVal = 0;

  while (greenVal < greenMax){
    for (int i=0; i<totalCols; i+=3){
      newRowBytes[0][i] = redVal;
      newRowBytes[0][i+1] = greenVal;
      newRowBytes[0][i+2] = blueVal;
      newRowBytes[1][i] = redVal;
      newRowBytes[1][i+1] = greenVal;
      newRowBytes[1][i+2] = blueVal;
    }
    greenVal += changeRate;
    tlcRow(0);
    tlcRow(1);
  }
  delay(500);
  greenVal = greenMax;

  while (redVal > -1){
    for (int i=0; i<totalCols; i+=3){
      newRowBytes[0][i] = redVal;
      newRowBytes[0][i+1] = greenVal;
      newRowBytes[0][i+2] = blueVal;
      newRowBytes[1][i] = redVal;
      newRowBytes[1][i+1] = greenVal;
      newRowBytes[1][i+2] = blueVal;
    }
    redVal -= changeRate/2;
    tlcRow(0);
    tlcRow(1);
  }
  delay(500);
  redVal = 0;

  while (blueVal < blueMax){
    for (int i=0; i<totalCols; i+=3){
      newRowBytes[0][i] = redVal;
      newRowBytes[0][i+1] = greenVal;
      newRowBytes[0][i+2] = blueVal;
      newRowBytes[1][i] = redVal;
      newRowBytes[1][i+1] = greenVal;
      newRowBytes[1][i+2] = blueVal;
    }
    blueVal += changeRate;
    tlcRow(0);
    tlcRow(1);
  }
  delay(500);
  blueVal = 255;

  while (greenVal > -1){
    for (int i=0; i<totalCols; i+=3){
      newRowBytes[0][i] = redVal;
      newRowBytes[0][i+1] = greenVal;
      newRowBytes[0][i+2] = blueVal;
      newRowBytes[1][i] = redVal;
      newRowBytes[1][i+1] = greenVal;
      newRowBytes[1][i+2] = blueVal;
    }
    greenVal -= changeRate;
    tlcRow(0);
    tlcRow(1);
  }
  delay(500);
  greenVal = 0;

  while (blueVal > -1){
    for (int i=0; i<totalCols; i+=3){
      newRowBytes[0][i] = redVal;
      newRowBytes[0][i+1] = greenVal;
      newRowBytes[0][i+2] = blueVal;
      newRowBytes[1][i] = redVal;
      newRowBytes[1][i+1] = greenVal;
      newRowBytes[1][i+2] = blueVal;
    }
    blueVal -= changeRate;
    tlcRow(0);
    tlcRow(1);
  }

  // To ensure 0,0,0
  for (int i=0; i<totalCols; i+=3){
    newRowBytes[0][i] = 0;
    newRowBytes[0][i+1] = 0;
    newRowBytes[0][i+2] = 0;
    newRowBytes[1][i] = 0;
    newRowBytes[1][i+1] = 0;
    newRowBytes[1][i+2] = 0;
  }
  tlcRow(0);
  tlcRow(1);
  tlcRow(2);
  tlcRow(3);
  tlcRow(4);
  tlcRow(5);
  tlcRow(6);
  tlcRow(7);
  tlcRow(8);
  tlcRow(9);
  tlcRow(10);
  tlcRow(11);
  tlcRow(12);
  tlcRow(13);
  tlcRow(14);
  tlcRow(15);
  updateOutputs();
  delay(5000);
}

// Sets different colour to the columns and shifts them over
// Old function made for 5x2 prototype
void rainbowShift(){
  static boolean setFunction = true;  // first time through function, set it up
  int val = 0;
  int oldBlue1,oldGreen1,oldRed1,oldBlue0,oldGreen0,oldRed0;
  if (setFunction){
    newRowBytes[0][0] = 0;//blue
    newRowBytes[0][1] = 0;
    newRowBytes[0][2] = blueMax;

    newRowBytes[0][3] = 0;//green
    newRowBytes[0][4] = greenMax;
    newRowBytes[0][5] = 0;

    newRowBytes[0][6] = redMax;//orange
    newRowBytes[0][7] = 0.1*greenMax;
    newRowBytes[0][8] = 0;

    newRowBytes[0][9] = redMax;//red
    newRowBytes[0][10] = 0;
    newRowBytes[0][11] = 0;

    newRowBytes[0][12] = redMax;//purple
    newRowBytes[0][13] = 0;
    newRowBytes[0][14] = blueMax;


    newRowBytes[1][0] = 0;//blue
    newRowBytes[1][1] = 0;
    newRowBytes[1][2] = blueMax;

    newRowBytes[1][3] = 0;//green
    newRowBytes[1][4] = greenMax;
    newRowBytes[1][5] = 0;

    newRowBytes[1][6] = redMax;//orange
    newRowBytes[1][7] = 0.1*greenMax;
    newRowBytes[1][8] = 0;

    newRowBytes[1][9] = redMax;//red
    newRowBytes[1][10] = 0;
    newRowBytes[1][11] = 0;

    newRowBytes[1][12] = redMax;//purple
    newRowBytes[1][13] = 0;
    newRowBytes[1][14] = blueMax;

    setFunction = false;  // done setup
    delay(2000);
  }
  else{// Shift row 0 data left and row 1 data right
    //Cycle Colours Right
    oldRed0 = newRowBytes[0][totalCols-3];
    oldGreen0 = newRowBytes[0][totalCols-2];
    oldBlue0 = newRowBytes[0][totalCols-1];
    shiftRight(0);
    newRowBytes[0][0] = oldRed0;
    newRowBytes[0][1] = oldGreen0;
    newRowBytes[0][2] = oldBlue0 ;

    //Cycle Colours Left
    //    oldBlue0 = newRowBytes[0][0];
    //    oldGreen0 = newRowBytes[0][1];
    //    oldRed0 = newRowBytes[0][2];
    //    shiftLeft();
    //    newRowBytes[0][totalCols-3] = oldBlue0;
    //    newRowBytes[0][totalCols-2] = oldGreen0;
    //    newRowBytes[0][totalCols-1] = oldRed0;

    oldRed1 = newRowBytes[1][0];
    oldGreen1 = newRowBytes[1][1];
    oldBlue1 = newRowBytes[1][2];
    shiftLeft(1);
    newRowBytes[1][totalCols-3] = oldRed1;
    newRowBytes[1][totalCols-2] = oldGreen1;
    newRowBytes[1][totalCols-1] = oldBlue1;
  }
  tlcRow(0);
  tlcRow(1);
  delay(1000);

}

// Shift all outputs left (ch1->ch0/ch1->ch0/etc.)
void shiftLeft(int row){
  for (int i=0; i<totalCols-3; i++){//-1 because not using all 16 outputs
    newRowBytes[row][i] = newRowBytes[row][i+3];
  }
}

// Shift all outputs left (ch1->ch0/ch1->ch0/etc.)
void shiftRight(int row){
  for (int i=totalCols-1; i>=3; i--){
    newRowBytes[row][i] = newRowBytes[row][i-3];
  }
}

// Shift Register Functions \\
void setupRegisters(){// Set row0 outpput LOW and the rest HIGH
    registers[0] = LOW;
//  registers[-1] = LOW;
  for (int i=0; i<totalRows-1; i++){
    registers[i] = HIGH;
  }
  PORTC &= ~(1<<7);
  PORTC &= ~(1<<4);
  for (int i=0; i<totalRows; i++){
    PORTC &= ~(1<<5);
    PORTC |= 1<<6;//sethigh
    PORTC |= 1<<5;
    Serial.println(registers[i]);
  }
  Serial.println("----------");
  PORTC |= 1<<7;
  PORTC |= 1<<4;
}

void nextRow(){// Shift data in and set new data bit as HIGH, unless at row0
  PORTC &= ~(1<<7);
  PORTC &= ~(1<<4);
  PORTC &= ~(1<<5);
  if (displayRow == totalRows-1){
    PORTC &= ~(1<<6);// clear low
  }
  else{
    PORTC |= 1<<6;//set high
  }
  PORTC |= 1<<5;
  PORTC |= 1<<7;
  PORTC |= 1<<4; 
  displayRow++;
  if (displayRow == totalRows){
    displayRow = 0;
  }
  delayMicroseconds(1000);
}
//--------------------------------------\\

// Base function from kdarrah. Changed for different type of data addressing and multiplexing
// Converts 8-bit data to 12-bit
void tlcRow(int updateRow){// TLC to UPDATE TLC to UPDATE TLC to UPDATE TLC to UPDATE
  int value;
  for (int i=0; i<totalCols; i++){
    value = map(newRowBytes[updateRow][i],0,256,0,4096)*brightness;  // Adjusts for resolution and brightness ratio
    
    // We need to convert the 12 bit value into an 8 bit BYTE, the SPI can't write 12bits
    if(value>4095)
      value=4095;
    if(value<0)
      value=0;

    //We figure out where in all of the bytes to write to, so we don't have to waste time
    // updating everything

    //12 bits into bytes, a start of 12 bits will either at 0 or 4 in a byte
    spibit=0;
    if(bitRead(i, 0))//if the read of the value is ODD, the start is at a 4
      spibit=4;

    //This is a simplification of channel * 12 bits / 8 bits
    spibyte = int((i)*3/2);//this assignes which byte the 12 bit value starts in

    for(chbit=0; chbit<12; chbit++, spibit++){// start right at where the update will go
      if(spibit==8){//during the 12 bit cycle, the limit of byte will be reached
        spibyte++;//roll into the next byte
        spibit=0;//reset the bit count in the byte
      }
      if(bitRead(value, chbit))//check the value for 1's and 0's
        bitSet(transferBytes[updateIndex][updateRow][spibyte], spibit);//transferbyte is what is written to the TLC
      else
        bitClear(transferBytes[updateIndex][updateRow][spibyte], spibit);
    }//0-12 bit loop
  }//  END OF TLC WRITE  END OF TLC WRITE  END OF TLC WRITE  END OF TLC WRITE  END OF TLC WRITE
}







//}//  END OF TLC WRITE  END OF TLC WRITE  END OF TLC WRITE  END OF TLC WRITE  END OF TLC WRITE
//*******************************************************************************************

void DotCorrection(){//  DOT Correction  DOT Correction  DOT Correction  DOT Correction
  // digitalWrite is slow so mmanipulate port directly. VPRG is digital pin 4
  // Pin 4 is PD4. Port D, Pin 4. PortD, use bitwise OR with a 1, at position 4. Writing a 1 to pin 4
  PORTH |= 1<<5;//VPRG to DC Mode HIGH
  spibyte=0;//reset our variables
  spibit=0;
  // SPI port can only write bytes (8-bits) but each channel needs 6-bit number for DC and must be 
  // sent continuously (one continuous chain)
  for(ch=0; ch<totalCols; ch++){// 6 bit a piece x 32 Outputs
    for(chbit=0; chbit<6; chbit++){
      if(spibit==8){
        spibyte++;
        spibit=0;
      }
      // Checks DC value (initially set to 63), converts it to binary and check all 6 bits (2^6=64) 
      // and set corresponding value in transferbyte (the 
      if(bitRead(DCvalue[ch], chbit))//all 6 bits
        bitSet(transferBytes[0][0][spibyte], spibit);//setting bit 7 of transfer byte
      else
        bitClear(transferBytes[0][0][spibyte], spibit);
      spibit++;
    }//i 
  }//j
  SPI.begin();
  // Start transferring MSB
  for(j=spibyte; j>=0; j--){
    SPI.transfer(transferBytes[0][0][j]);
  }
  // XLAT is PD2, PortD bit 2
  PORTH |= 1<<3;//XLAT the data in
  PORTH &= ~(1<<3);//XLAT data is in now
  PORTH &= ~(1<<5);//VPRG is good to go into normal mode LOW
}//  end of DOT Correction  end of DOT Correction  end of DOT Correction  end of DOT Correction
//*******************************************************************************************

// Switches display and update arrays 
void updateOutputs(){
  displayIndex = (displayIndex+1)%2;
  updateIndex = (updateIndex+1)%2;
}
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
